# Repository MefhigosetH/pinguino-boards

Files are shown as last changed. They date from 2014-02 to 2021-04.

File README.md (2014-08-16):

pinguino-boards
===============

Personal Pinguino-project OpenHardware schematics and boards.

For more info, please visit:

* Official site at http://www.pinguino.cc
* My personal blog at http://www.mefhigoseth.com.ar/p/pinguino.html

Notes:

* The schematics and boards are designed with Kicad 2012-nov-02 version.
* Master branch have the latest stable board design. Recomended for production. Test passed.
* Testing branch may have partial, incomplete or non-functional boards. Use at your own risk.

# pinguino-2550-v1

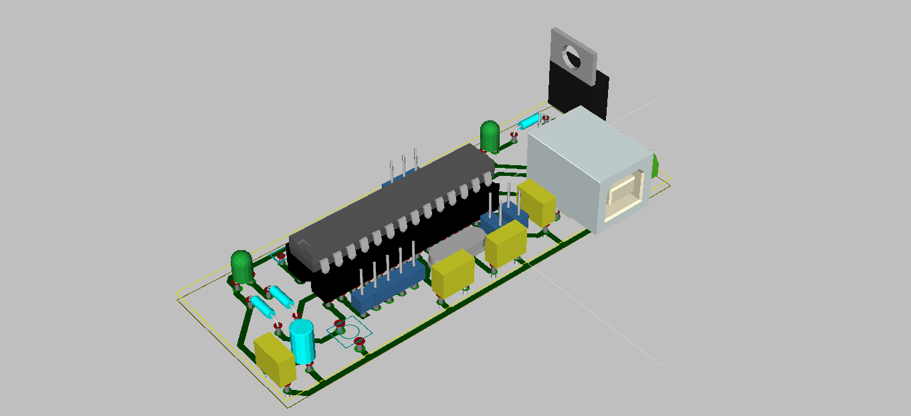
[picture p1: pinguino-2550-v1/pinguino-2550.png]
pinguino-2550-v1-3D-model


Pinguino board based on PIC18F2550. Features:

* Small form factor: 80x30 mm
* External power supply bornier.
* LM7805 1Amp 5v Positive voltaje regulator with 5-18v input.
* USB Self-powered or external swith, via jumper.
* Power (red) and User (green) 5mm led.
* Easy access to all I/O port, including PWM and UART.
* Easy home-based build the board (DIY).

# pinguino-2550-v2

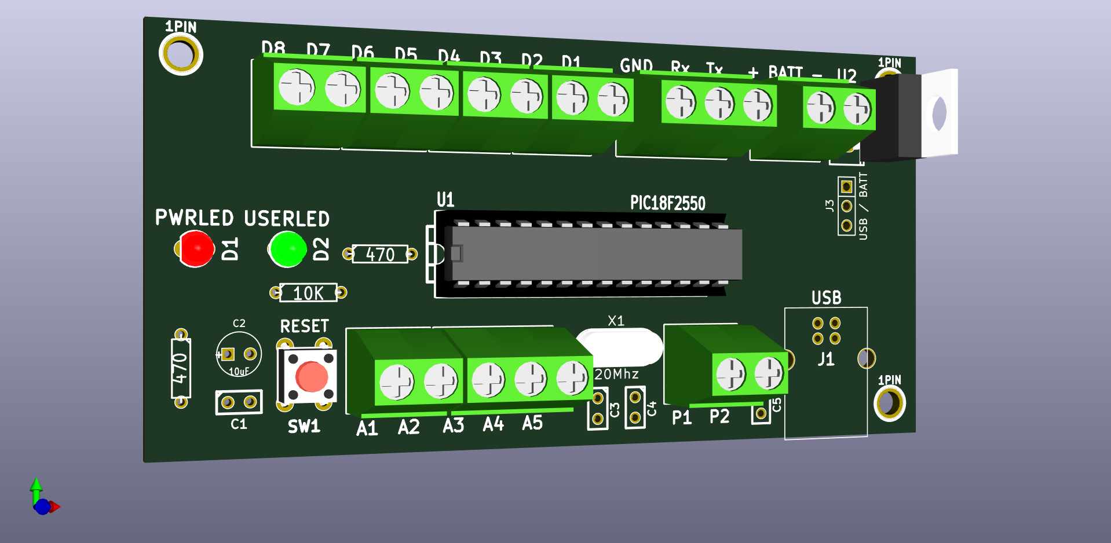
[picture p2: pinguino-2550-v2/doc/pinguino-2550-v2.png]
pinguino-2550-v2-3D-model


Pinguino board based on PIC18F2550. Features:

* Form factor: 100x50 mm.
* External power supply bornier.
* LM7805 1Amp 5v Positive voltaje regulator with 5-18v input voltaje.
* USB Self-powered or external BATT select jumper.
* Power (red) and User (green) 3mm led.
* Easy access to all I/O port including PWM and UART, via 8A borniers.
* Easy home-based build the board (DIY).

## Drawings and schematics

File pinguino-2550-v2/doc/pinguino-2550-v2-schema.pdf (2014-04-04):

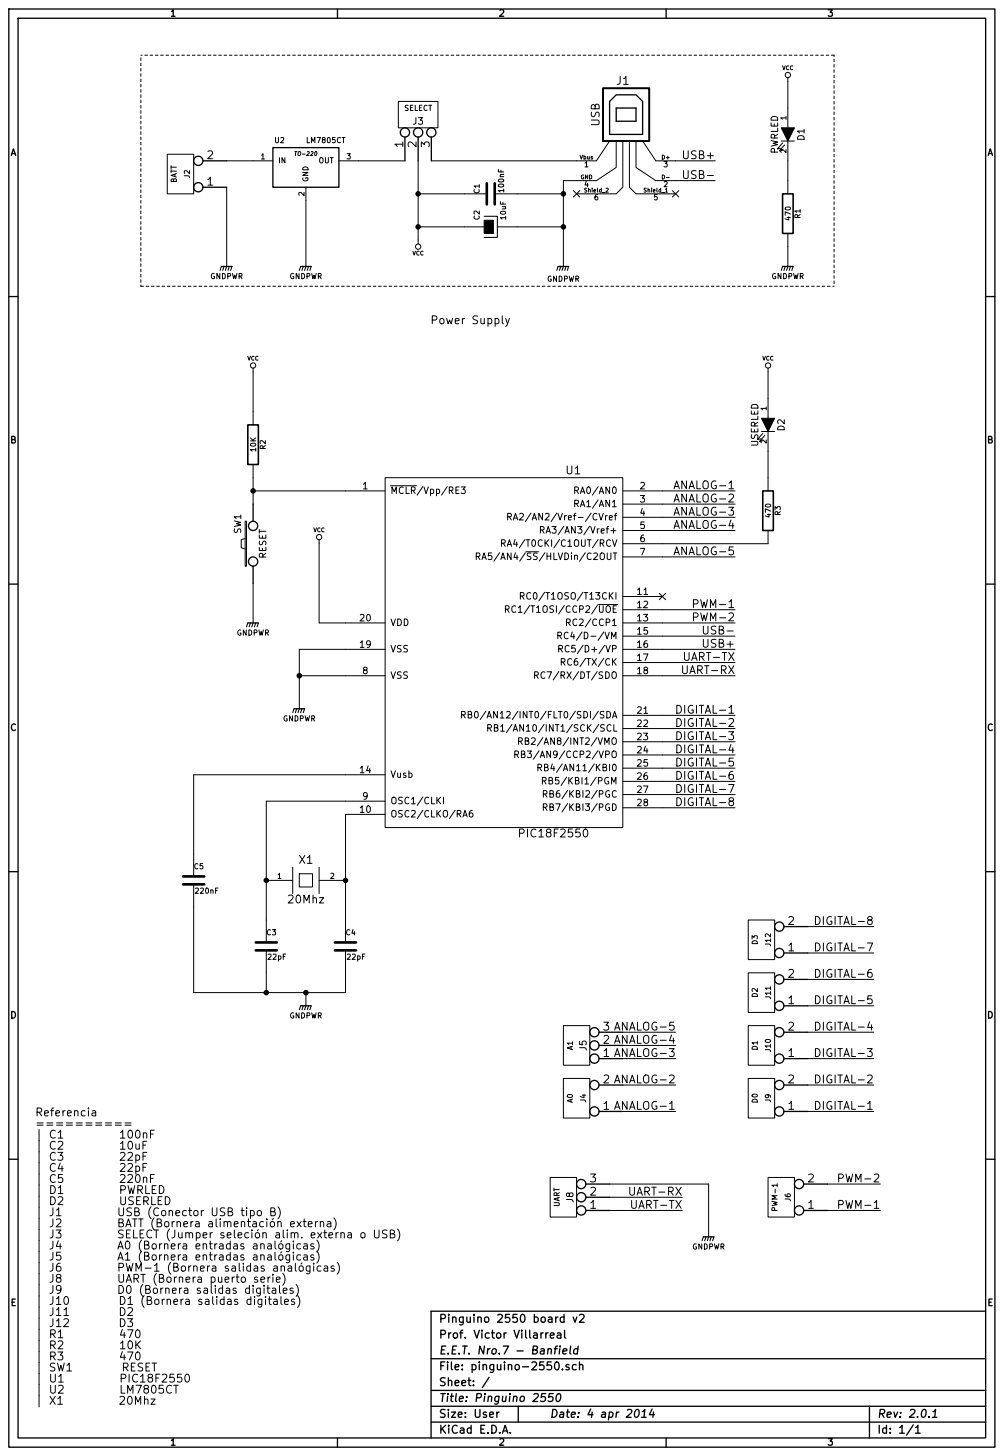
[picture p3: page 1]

1 2 D1 PWRLED VCC GNDPWR GNDPWR

1 2 D2 USERLED VCC UART-RX UART-TX USB-

Sheet: / E.E.T. Nro.7 - Banfield Prof. Victor Villarreal Pinguino 2550 board v2

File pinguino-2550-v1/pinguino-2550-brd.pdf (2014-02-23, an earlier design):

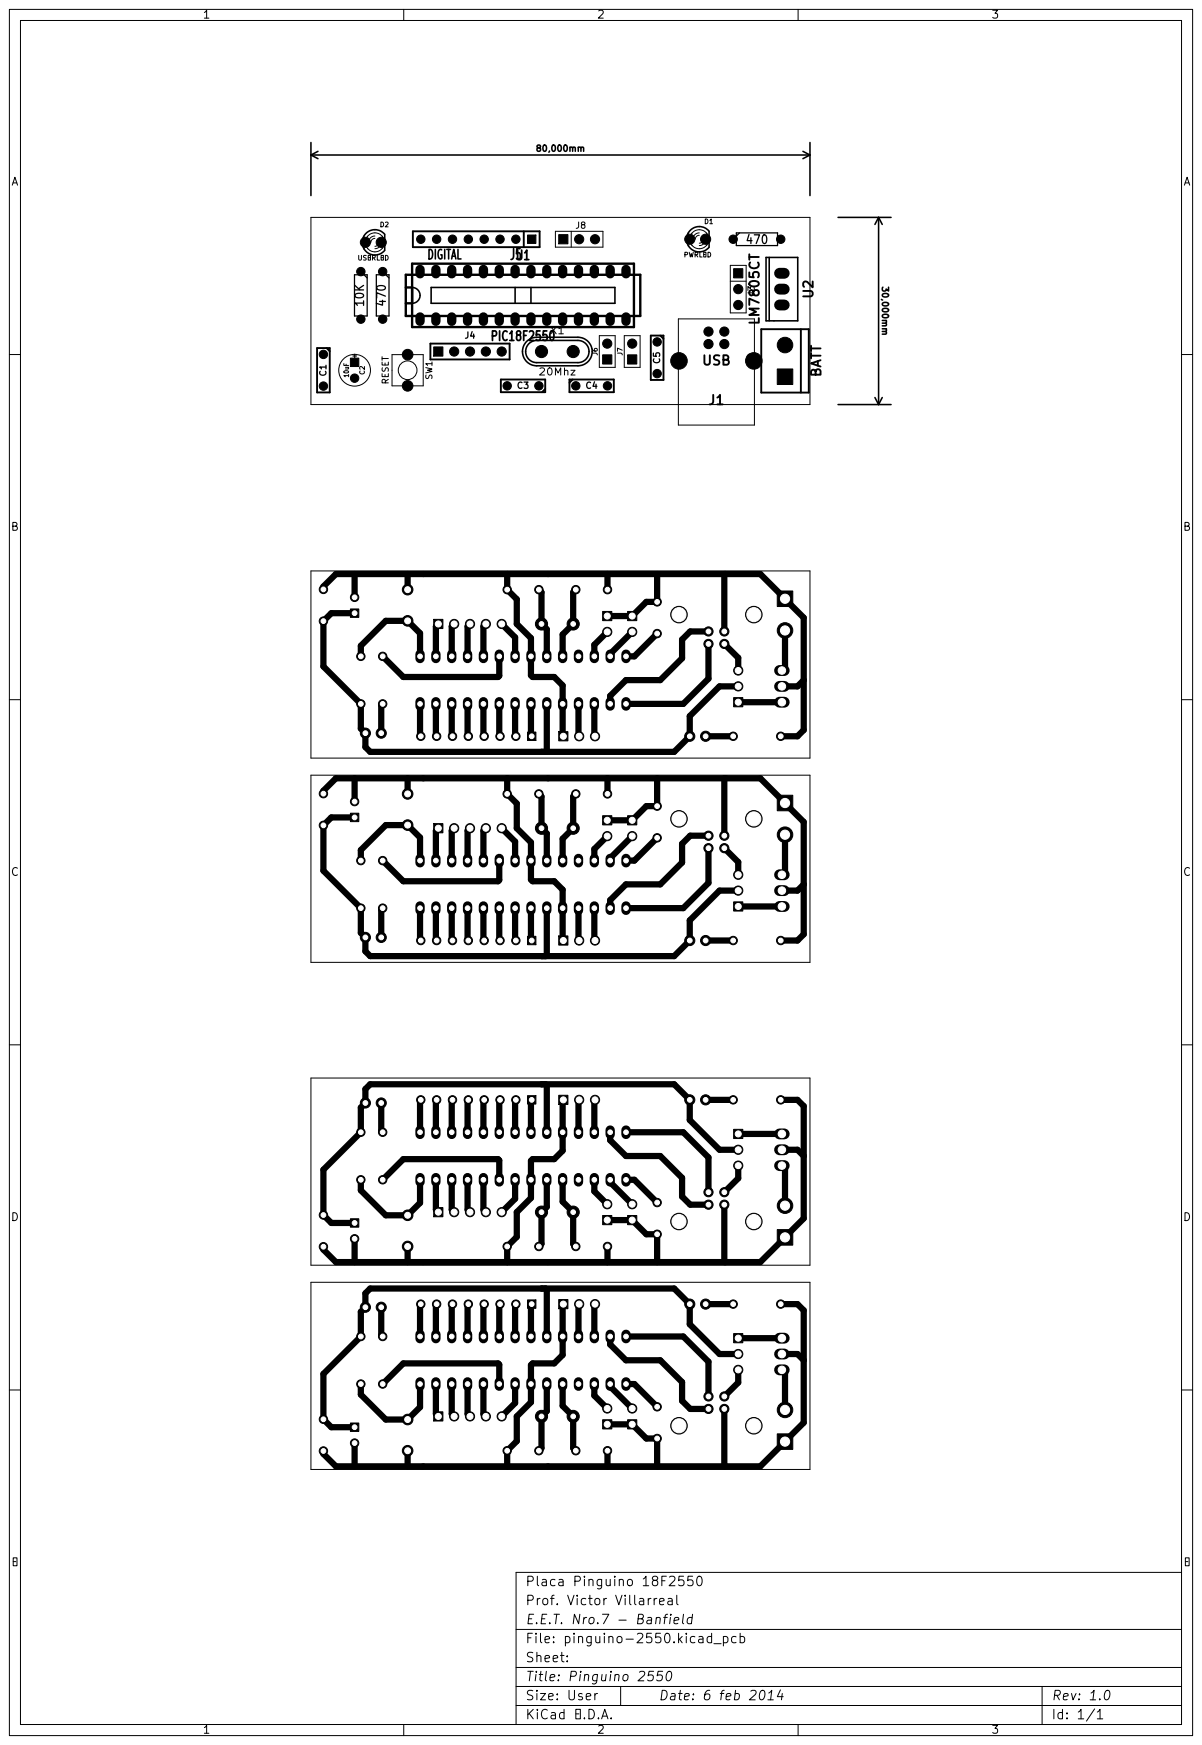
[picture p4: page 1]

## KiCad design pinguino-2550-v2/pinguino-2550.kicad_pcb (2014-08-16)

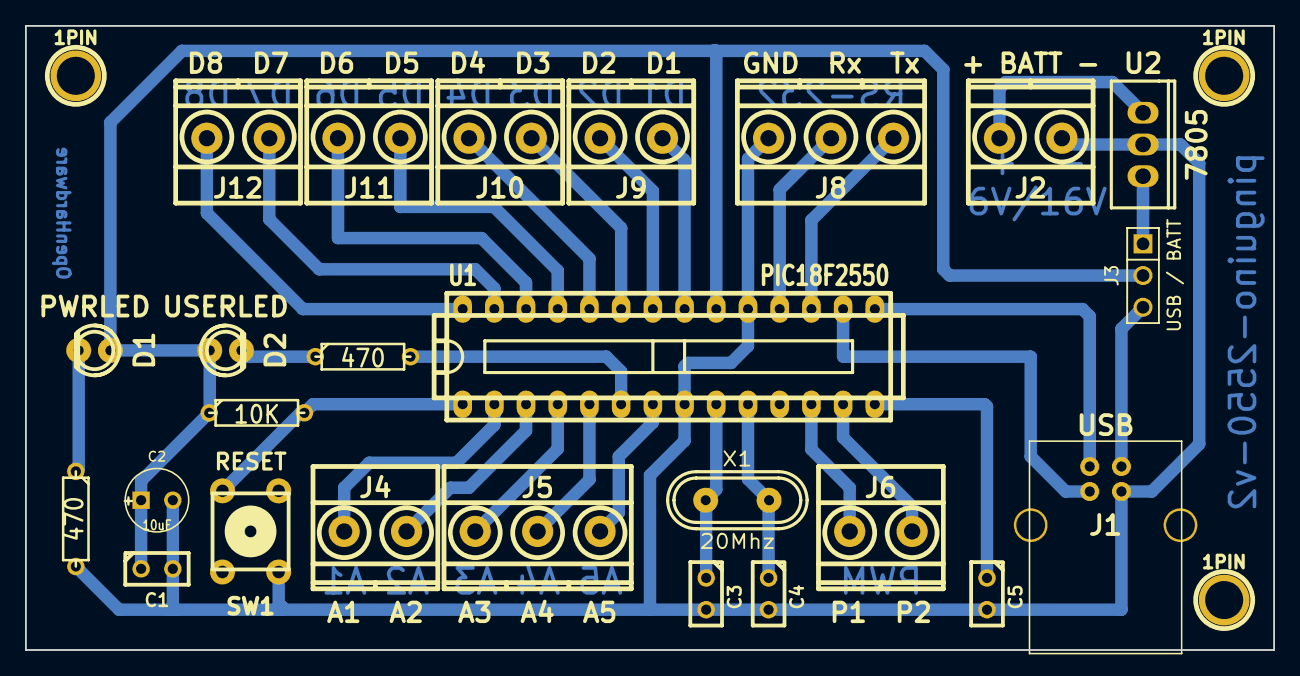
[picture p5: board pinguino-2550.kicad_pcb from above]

Board: 2 copper layers, 100.0 x 50.0 mm, 28 parts (0 on the bottom side), 31 nets.

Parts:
1PIN, 1PIN#2, 1PIN#3: P***; 1pin
C1: 100nF; C1
C2: 10uF; C1V5
C3, C4: 22pF; C1
C5: 220nF; C1
D1: PWRLED; led_3mm_red
D2: USERLED; led_3mm_green
J1: USB; USB_B
J2: + BATT -; mkds_1,5-2
J3: USB / BATT; PIN_ARRAY_3X1
J4: A1 A2; mkds_1,5-2
J5: A3 A4 A5; mkds_1,5-3
J6: P1 P2; mkds_1,5-2
J8: GND Rx Tx; mkds_1,5-3
J9: D2 D1; mkds_1,5-2
J10: D4 D3; mkds_1,5-2
J11: D6 D5; mkds_1,5-2
J12: D8 D7; mkds_1,5-2
R1, R3: 470; R3
R2: 10K; R3
SW1: RESET; PCB_PUSH
U1: PIC18F2550; dil_28-300_socket
U2: 7805; to220_std
X1: 20Mhz; crystal_hc-49s

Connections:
/ANALOG-1: J4.1, U1.2
/ANALOG-2: J4.2, U1.3
/ANALOG-3: J5.1, U1.4
/ANALOG-4: J5.2, U1.5
/ANALOG-5: J5.3, U1.7
/DIGITAL-1: J9.1, U1.21
/DIGITAL-2: J9.2, U1.22
/DIGITAL-3: J10.1, U1.23
/DIGITAL-4: J10.2, U1.24
/DIGITAL-5: J11.1, U1.25
/DIGITAL-6: J11.2, U1.26
/DIGITAL-7: J12.1, U1.27
/DIGITAL-8: J12.2, U1.28
/PWM-1: J6.1, U1.12
/PWM-2: J6.2, U1.13
/UART-RX: J8.2, U1.18
/UART-TX: J8.1, U1.17
/USB+: J1.3, U1.16
/USB-: J1.2, U1.15
GNDPWR: C1.2, C2.2, C3.2, C4.2, C5.2, J1.4, J2.1, J8.3, R1.2, SW1.1, U1.8, U1.19, U2.2
unnamed: R2.2, SW1.2, U1.1
unnamed: R3.2, U1.6
unnamed: D2.2, R3.1
unnamed: J2.2, U2.1
unnamed: J3.1, U2.3
unnamed: J1.1, J3.3
unnamed: C5.1, U1.14
unnamed: C3.1, U1.9, X1.1
unnamed: C4.1, U1.10, X1.2
unnamed: D1.2, R1.1
VCC: C1.1, C2.1, D1.1, D2.1, J3.2, R2.1, U1.20

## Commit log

2014-02-23 Added pinguino-2550-v1 board
    [pinguino-2550.kicad_pcb, pinguino-2550.sch]
2014-04-03 First commit pinguino-2550-v2
    [pinguino-2550.kicad_pcb, pinguino-2550.sch]
2014-04-04 Added BoM. Fixed pcbnew paper size.
    [pinguino-2550.kicad_pcb, pinguino-2550.sch]
2014-08-15 Cupper layer text mirroring.
    [pinguino-2550.kicad_pcb]
2014-08-16 Fixed bornier modules text.
    [pinguino-2550.kicad_pcb]
2014-08-16 Updated README.md: Added pinguino-2550-v2 board.
2014-08-16 Updated README.md: Added 3D board models.
2021-04-24 feat(3d): Updated 3d model for pinguino-2550-v2 board.
